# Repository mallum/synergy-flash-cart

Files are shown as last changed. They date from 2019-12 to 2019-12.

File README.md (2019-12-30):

# Synergy Flash Cart

A 'Flash Cart' for your DK Synergy synth... select & load ROM cartridge .crt files from the root of an SD card.

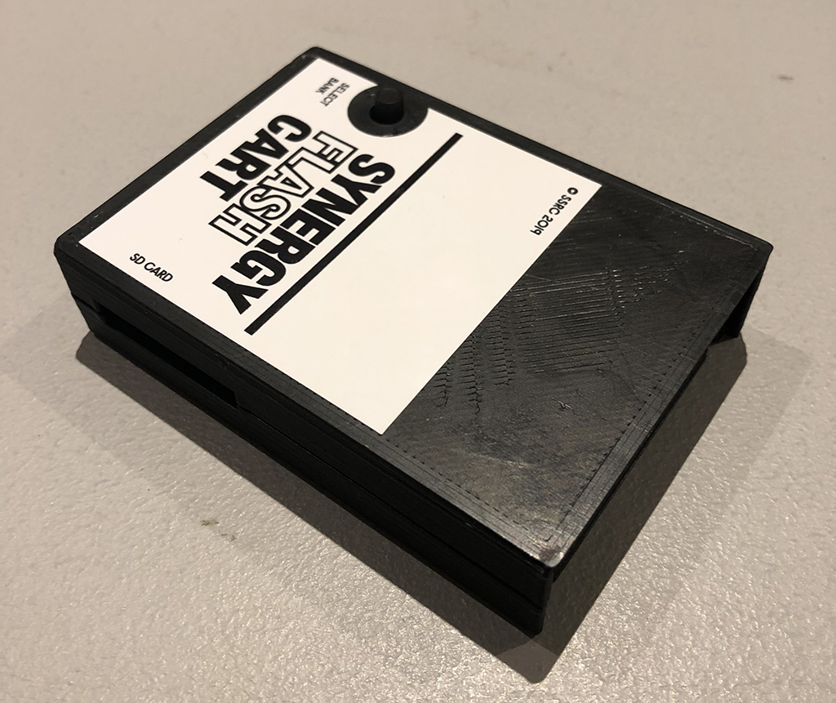
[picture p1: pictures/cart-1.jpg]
Image of Flash Cart


A single button cycles between .crt files placed on root of a fat formatted sd card. Top backlit character display shows currently active crt file. 

This repository contains the schematics, BOM, source code and 3D print files for a cartridge.

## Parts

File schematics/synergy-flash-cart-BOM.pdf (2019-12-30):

### synergy-cart rev005

Qty | Parts | Value | Package | Part num / Description
1 | R6 | 0R | R0603
1 | R19 | 1k | R0603
10 | R1, R2, R3, R4, R5, R7, R8, R45, R47, R48 | 10K | R0603
1 | R10 | 100k | R0603
1 | R9 | 5k | RTRIM4G/J | TS53YJ502MR10 (or similar)
2 | C26, C29 | 18pF | C0603
1 | C20 | 10n | C0603
9 | C2, C5, C7, C18, C30, C32, C33, C35, C58 | 100n | C0603
1 | C8 | 1uf | C0603
2 | C22, C24 | 2.2uf | C0805
2 | C1, C6 | 10uf | CT3216 | CA45-106K016AT (16V) Tantalum
1 | IC7 | REG1117 | SOT223 | AMS1117-3.3 (or similar)
1 | UC1 | STM32F405RGT6 | TQFP-10X10-64 | STM32F405RGT6
1 | CN1 | | SDCARD_SMT_AMPH_160611 | Amphenol 1010031336802 (or similar - check footprint)
1 | X1 | 52746-16 | 52746-16 | FPC Connector ZIF for SMT 0.5mm contacts bottom / AFC07-S16FCC-00 (or similar))
1 | Y1 | 8Mhz | CRYSTAL-SMD-5.0MM-3.2MM-2 | 7A-8.00MAAJ-T (or similar)
1 | BANK_SEL | SWITCH-MOMENTARY-2PTH | TACTILE-PTH | NOT NEEDED (TL1105SPF250Q)
1 | LED | | CHIPLED_1206 | NOT NEEDED (debug)
1 | J3 | M05_NOSILK_1SQ | M05_NOSILK_1SQ | NOT NEEDED (programming header)
1 | RST | T1107A-6_3.8_2.5 | SW-TAKT_6X3.5_SMD | NOT NEEDED (reset switch)
1 | PWR | | 1X02 | NOT NEEDED (alt power source for programming)
1 | G-T-R | | 1X03 | NOT NEEDED (Debug serial port)
1 | SYNERGYCART | SYNERGY_CARTSYNER | SYNERGY_CART | NOT NEEDED (PCB layout)

Also needs display - buydisplay.com ERM801FS-1 , button cap Sifam PB04/51/000, printed case, m3 threaded insert, screw, sticker (ALL NOT NEEDED for pcb cart)

All caps at least 10v Ceramic unless specced. All resistors 1% at least 0.1 watt

1

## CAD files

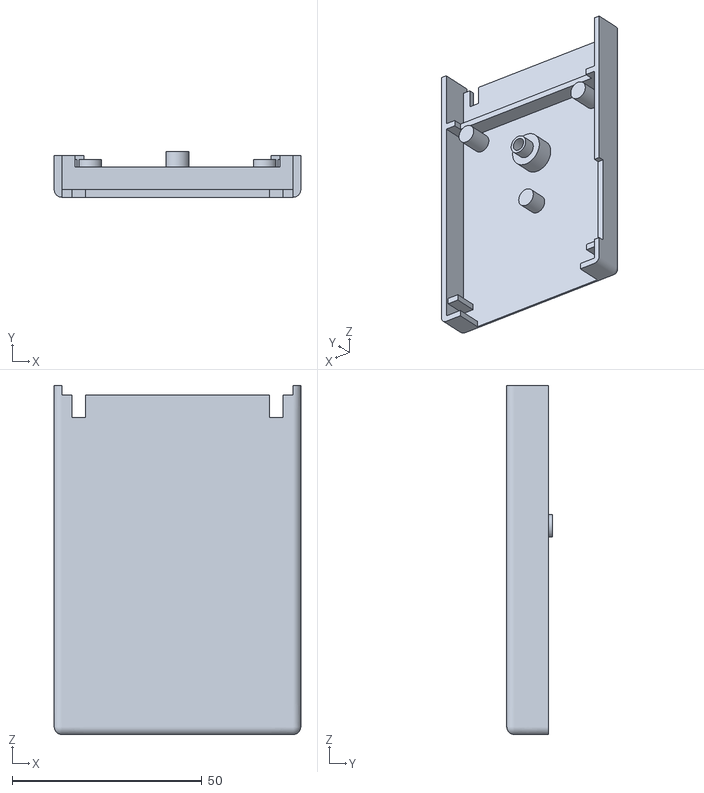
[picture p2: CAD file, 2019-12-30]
form/cart-bottom-v15.stl
65.0 x 12.0 x 92.0

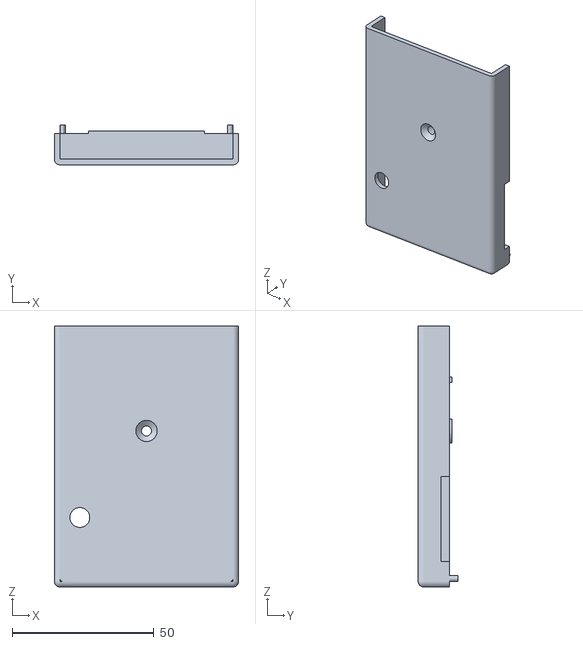
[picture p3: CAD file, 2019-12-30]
form/cart-top-v10.stl
65.0 x 14.0 x 92.0

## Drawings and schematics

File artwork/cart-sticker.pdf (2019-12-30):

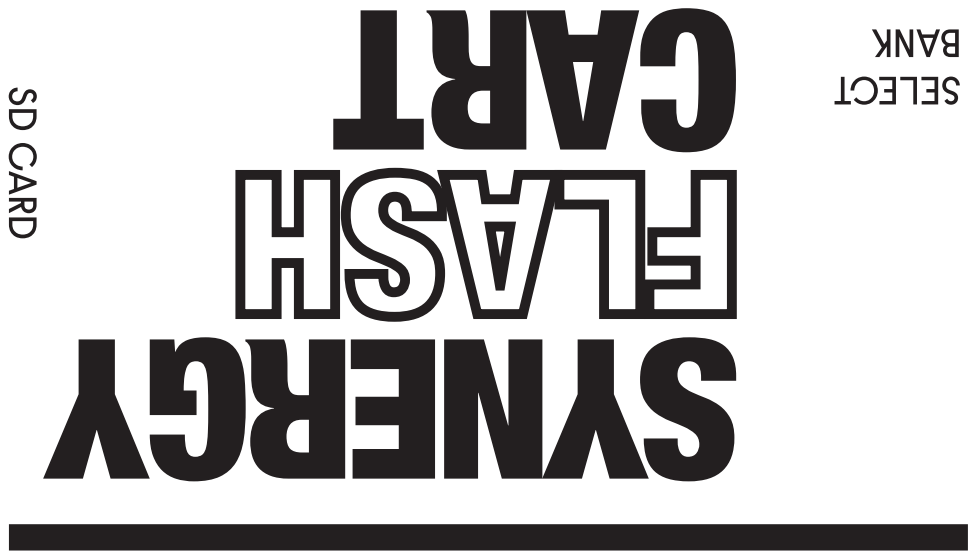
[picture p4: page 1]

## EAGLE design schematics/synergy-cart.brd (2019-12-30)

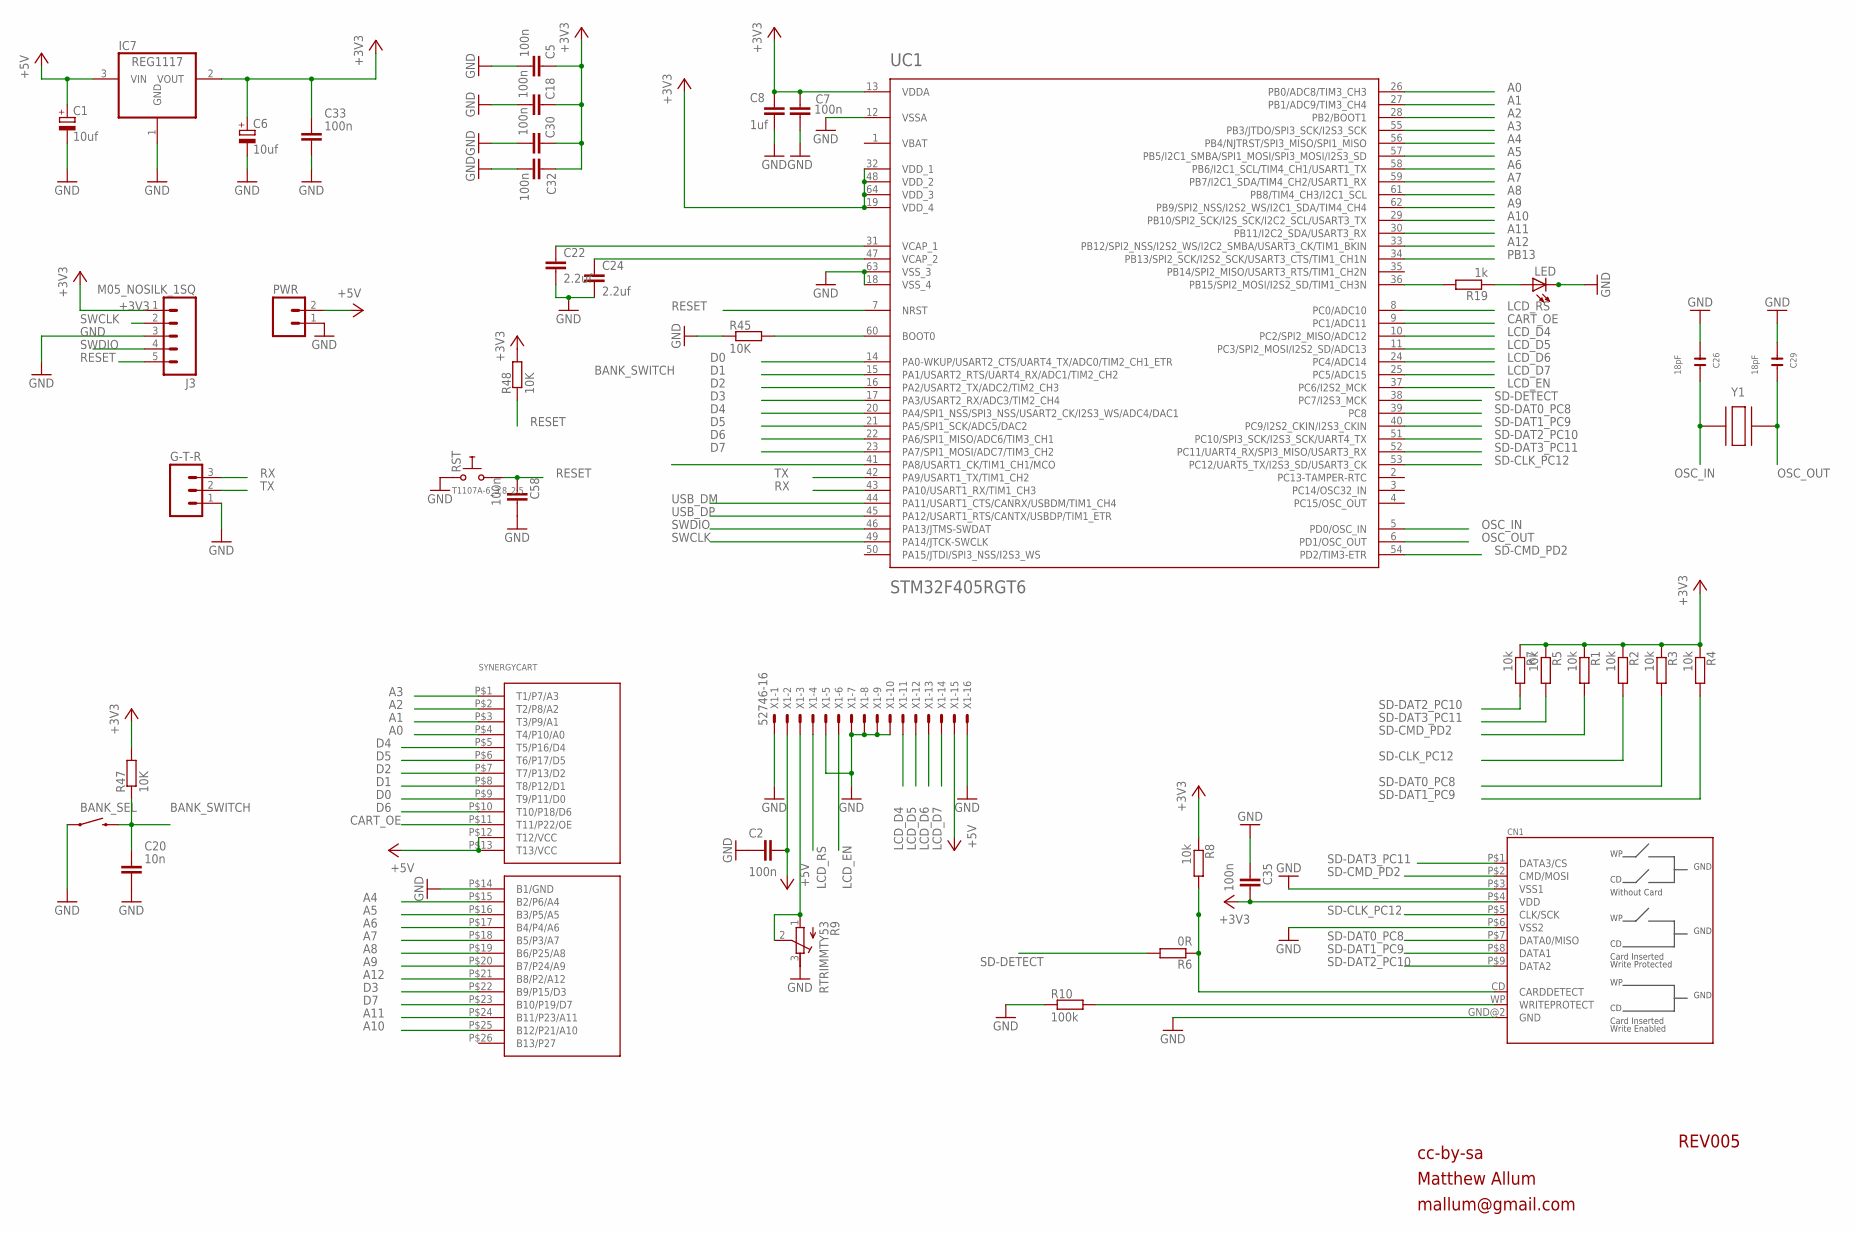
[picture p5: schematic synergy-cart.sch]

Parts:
BANK_SEL: SWITCH-MOMENTARY-2PTH; TACTILE-PTH
C1, C6: 10uf; CT3216
C2, C5, C7, C18, C30, C32, C33, C35, C58: 100n; C0603
C8: 1uf; C0603
C20: 10n; C0603
C22, C24: 2.2uf; C0805
C26, C29: 18pF; C0603
CN1: SDCARD160611; SDCARD_SMT_AMPH_160611
G-T-R: M03PTH; 1X03
IC7: REG1117; SOT223
J3: M05_NOSILK_1SQ
LED: LEDCHIPLED_1206; CHIPLED_1206
PWR: M02PTH; 1X02
R1, R2, R3, R4, R5, R7, R8: 10k; R0603
R6: 0R; R0603
R9: RTRIMMTY53; RTRIMTY53
R10: 100k; R0603
R19: 1k; R0603
R45, R47, R48: 10K; R0603
RST: T1107A-6_3.8_2.5; SW-TAKT_6X3.5_SMD
SYNERGYCART: SYNERGY_CARTSYNER; SYNERGY_CART
UC1: STM32F405RGT6; TQFP-10X10-64
X1: 52746-16
Y1: CRYSTAL-2; CRYSTAL-SMD-5.0MM-3.2MM-2

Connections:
+3V3: C5.1, C6.- (+), C7.1, C8.1, C18.1, C30.1, C32.1, C33.1, C35.1, CN1.P$4 (VDD), IC7.2 (VOUT), J3.1, R1.1, R2.1, R3.1, R4.1, R5.1, R7.1, R8.1, R47.2, R48.2, UC1.13 (VDDA), UC1.19 (VDD_4), UC1.32 (VDD_1), UC1.48 (VDD_2), UC1.64 (VDD_3)
+5V: C1.- (+), C2.1, IC7.3 (VIN), PWR.2, SYNERGYCART.P$12 (T12/VCC), SYNERGYCART.P$13 (T13/VCC), X1.2, X1.15
A0: SYNERGYCART.P$4 (T4/P10/A0), UC1.26 (PB0/ADC8/TIM3_CH3)
A1: SYNERGYCART.P$3 (T3/P9/A1), UC1.27 (PB1/ADC9/TIM3_CH4)
A2: SYNERGYCART.P$2 (T2/P8/A2), UC1.28 (PB2/BOOT1)
A3: SYNERGYCART.P$1 (T1/P7/A3), UC1.55 (PB3/JTDO/SPI3_SCK/I2S3_SCK)
A4: SYNERGYCART.P$15 (B2/P6/A4), UC1.56 (PB4/NJTRST/SPI3_MISO/SPI1_MISO)
A5: SYNERGYCART.P$16 (B3/P5/A5), UC1.57 (PB5/I2C1_SMBA/SPI1_MOSI/SPI3_MOSI/I2S3_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)
A6: SYNERGYCART.P$17 (B4/P4/A6), UC1.58 (PB6/I2C1_SCL/TIM4_CH1/USART1_TX)
A7: SYNERGYCART.P$18 (B5/P3/A7), UC1.59 (PB7/I2C1_SDA/TIM4_CH2/USART1_RX)
A8: SYNERGYCART.P$19 (B6/P25/A8), UC1.61 (PB8/TIM4_CH3/I2C1_SCL)
A9: SYNERGYCART.P$20 (B7/P24/A9), UC1.62 (PB9/SPI2_NSS/I2S2_WS/I2C1_SDA/TIM4_CH4)
A10: SYNERGYCART.P$25 (B12/P21/A10), UC1.29 (PB10/SPI2_SCK/I2S_SCK/I2C2_SCL/USART3_TX)
A11: SYNERGYCART.P$24 (B11/P23/A11), UC1.30 (PB11/I2C2_SDA/USART3_RX)
A12: SYNERGYCART.P$21 (B8/P2/A12), UC1.33 (PB12/SPI2_NSS/I2S2_WS/I2C2_SMBA/USART3_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)
BANK_SWITCH: BANK_SEL.3 (2), C20.1, R47.1, UC1.41 (PA8/USART1_CK/TIM1_CH1/MCO)
CART_OE: SYNERGYCART.P$11 (T11/P22/OE), UC1.9 (PC1/ADC11)
D0: SYNERGYCART.P$9 (T9/P11/D0), UC1.14 (PA0-WKUP/USART2_CTS/UART4_TX/ADC0/TIM2_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)
D1: SYNERGYCART.P$8 (T8/P12/D1), UC1.15 (PA1/USART2_RTS/UART4_RX/ADC1/TIM2_CH2)
D2: SYNERGYCART.P$7 (T7/P13/D2), UC1.16 (PA2/USART2_TX/ADC2/TIM2_CH3)
D3: SYNERGYCART.P$22 (B9/P15/D3), UC1.17 (PA3/USART2_RX/ADC3/TIM2_CH4)
D4: SYNERGYCART.P$5 (T5/P16/D4), UC1.20 (PA4/SPI1_NSS/SPI3_NSS/USART2_CK/I2S3_WS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)
D5: SYNERGYCART.P$6 (T6/P17/D5), UC1.21 (PA5/SPI1_SCK/ADC5/DAC2)
D6: SYNERGYCART.P$10 (T10/P18/D6), UC1.22 (PA6/SPI1_MISO/ADC6/TIM3_CH1)
D7: SYNERGYCART.P$23 (B10/P19/D7), UC1.23 (PA7/SPI1_MOSI/ADC7/TIM3_CH2)
GND: BANK_SEL.1, C1.+ (-), C2.2, C5.2, C6.+ (-), C7.2, C8.2, C18.2, C20.2, C22.2, C24.2, C26.2, C29.2, C30.2, C32.2, C33.2, C35.2, C58.1, CN1.GND@2 (GND), CN1.P$3 (VSS1), CN1.P$6 (VSS2), G-T-R.1, IC7.1 (GND), J3.3, LED.C, PWR.1, R9.3 (E), R10.1, R45.1, RST.P$1 (0), SYNERGYCART.P$14 (B1/GND), UC1.12 (VSSA), UC1.18 (VSS_4), UC1.63 (VSS_3), X1.1, X1.5, X1.7, X1.8, X1.9, X1.10, X1.16
LCD_D4: UC1.10 (PC2/SPI2_MISO/ADC12), X1.11
LCD_D5: UC1.11 (PC3/SPI2_MOSI/I2S2_SD/ADC13), X1.12
LCD_D6: UC1.24 (PC4/ADC14), X1.13
LCD_D7: UC1.25 (PC5/ADC15), X1.14
LCD_EN: UC1.37 (PC6/I2S2_MCK), X1.6
LCD_RS: UC1.8 (PC0/ADC10), X1.4
unnamed: R19.2, UC1.36 (PB15/SPI2_MOSI/I2S2_SD/TIM1_CH3N)
unnamed: R45.2, UC1.60 (BOOT0)
unnamed: CN1.CD (CARDDETECT), R6.1, R8.2
unnamed: CN1.WP (WRITEPROTECT), R10.2
unnamed: R9.1 (A), R9.2 (S), X1.3
unnamed: LED.A, R19.1
unnamed: C22.1, UC1.31 (VCAP_1)
unnamed: C24.1, UC1.47 (VCAP_2)
OSC_IN: C26.1, UC1.5 (PD0/OSC_IN), Y1.2
OSC_OUT: C29.1, UC1.6 (PD1/OSC_OUT), Y1.1
PB13: UC1.34 (PB13/SPI2_SCK/I2S2_SCK/USART3_CTS/TIM1_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)
RESET: C58.2, J3.5, R48.1, RST.P$2 (1), UC1.7 (NRST)
RX: G-T-R.3, UC1.43 (PA10/USART1_RX/TIM1_CH3)
SD-CLK_PC12: CN1.P$5 (CLK/SCK), R2.2, UC1.53 (PC12/UART5_TX/I2S3_SD/USART3_CK)
SD-CMD_PD2: CN1.P$2 (CMD/MOSI), R1.2, UC1.54 (PD2/TIM3-ETR)
SD-DAT0_PC8: CN1.P$7 (DATA0/MISO), R3.2, UC1.39 (PC8)
SD-DAT1_PC9: CN1.P$8 (DATA1), R4.2, UC1.40 (PC9/I2S2_CKIN/I2S3_CKIN)
SD-DAT2_PC10: CN1.P$9 (DATA2), R7.2, UC1.51 (PC10/SPI3_SCK/I2S3_SCK/UART4_TX)
SD-DAT3_PC11: CN1.P$1 (DATA3/CS), R5.2, UC1.52 (PC11/UART4_RX/SPI3_MISO/USART3_RX)
SD-DETECT: R6.2, UC1.38 (PC7/I2S3_MCK)
SWCLK: J3.2, UC1.49 (PA14/JTCK-SWCLK)
SWDIO: J3.4, UC1.46 (PA13/JTMS-SWDAT)
TX: G-T-R.2, UC1.42 (PA9/USART1_TX/TIM1_CH2)
USB_DM: UC1.44 (PA11/USART1_CTS/CANRX/USBDM/TIM1_CH4)
USB_DP: UC1.45 (PA12/USART1_RTS/CANTX/USBDP/TIM1_ETR)
VBAT: UC1.1 (VBAT)

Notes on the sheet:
REV005
cc-by-sa
Matthew Allum
mallum@gmail.com

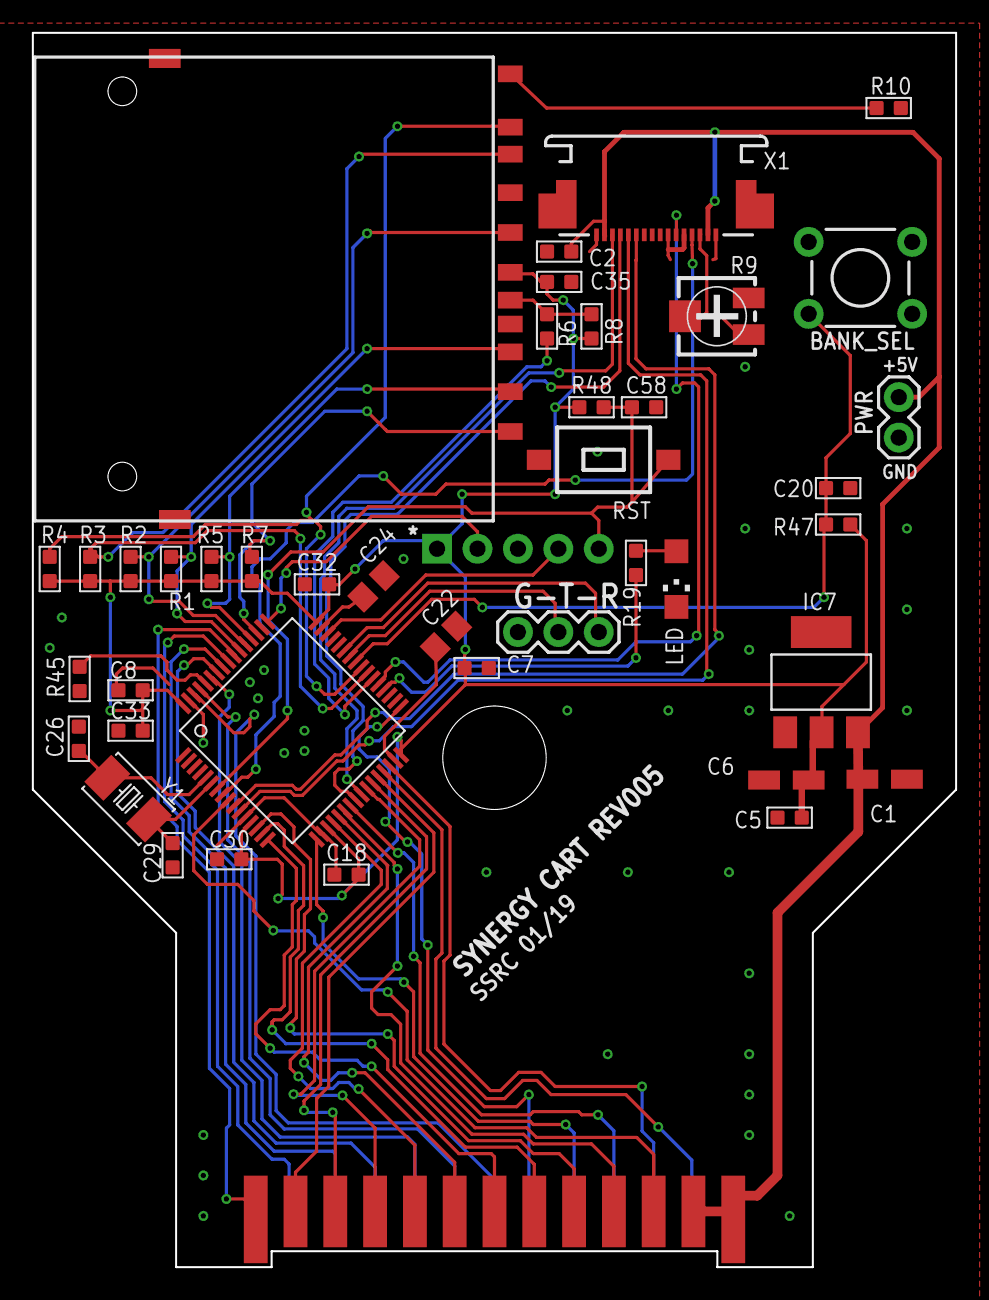
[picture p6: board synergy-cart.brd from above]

Board: 2 copper layers, 58.0 x 77.5 mm, 43 parts (0 on the bottom side), 54 nets.

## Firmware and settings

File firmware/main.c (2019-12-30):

/* 

Copyright (c) 2019 Matthew Allum / Allum & Co ltd. 

All rights reserved.

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
*/

#include <stdbool.h>
#include <math.h>
#include <limits.h>
#include <string.h>

#include "hw.h"

#include "sdcard.h"
#include "ff.h"
#include "diskio.h"

#define MAX_FILENAME_LEN 128
#define MAX_CART_FILENAMES 128

typedef struct _SynergyCartFile
{
  char      filename[MAX_FILENAME_LEN];
  uint16_t  size;
} SynergyCartFile;

SynergyCartFile _cart_files[MAX_CART_FILENAMES];
uint16_t _n_cart_files = 0;

#define CCRAM_SIZE (64 * 1024)
uint8_t _ccram[CCRAM_SIZE] __attribute__((section(".ccmram")));

#define ADDR_IN GPIOB->IDR
#define DATA_OUT GPIOA->ODR

void sort_carts()
{
  int i,j;

  for (i=0;i<_n_cart_files;i++)
    for (j=i+1;j<_n_cart_files; j++)
      if (strcmp(_cart_files[i].filename, _cart_files[j].filename) > 0)
	{
	  SynergyCartFile tmp;
	  /* meh.. */
	  memcpy((void*)tmp.filename, (void*)_cart_files[i].filename, MAX_FILENAME_LEN);
	  tmp.size = _cart_files[i].size;
	  memcpy((void*)_cart_files[i].filename, (void*)_cart_files[j].filename, MAX_FILENAME_LEN);
	  _cart_files[i].size = _cart_files[j].size;
	  memcpy((void*)_cart_files[j].filename, (void*)tmp.filename , MAX_FILENAME_LEN);
	  _cart_files[i].size = tmp.size;
	}
}

bool sd_load_cart(int index)
{
  volatile FATFS fs;   

  FIL fsrc;      
  uint32_t br, i = 0;
  FRESULT res;
  FILINFO finfo;
  uint8_t buf[256];
  char txt[9];
  
  res = f_open(&fsrc, _cart_files[index].filename, FA_OPEN_EXISTING | FA_READ);

  if (res != FR_OK)
    {
      tfp_printf("f_open failed\n");
      hw_lcd_clear();
      hw_lcd_put_str("SD Fail");
      return false;
    }

  do
    {
      res = f_read(&fsrc, (uint8_t *)buf, 256, (unsigned int*)&br);
      memcpy(&_ccram[i], buf, br);
      i += br;
    }
  while (res == FR_OK && br == 256 && i < CCRAM_SIZE);

  tfp_printf("read %i\n", i);

  /* fixme pull the name from the actual cart file itself */
  i = strlen(_cart_files[index].filename)-4;
  if (i>9) i=9;
  tfp_snprintf(txt, 9, "%s", _cart_files[index].filename+1);
  txt[i-1] = '\0';

  hw_lcd_clear();
  hw_lcd_put_str(txt);

  _cart_files[index].size = br;
  
  f_close(&fsrc);

  return true;
}

bool sd_get_carts(void)
{
  FATFS fs;  
  FIL fsrc;  
  uint32_t br, i; 
  FRESULT res;
  DIR dir;
  FILINFO fno;

  _n_cart_files = 0;
  
  disk_initialize(0);
  
  res = f_mount(0, &fs);

  if (res != FR_OK)
    {
      hw_lcd_clear();
      hw_lcd_put_str("SD Err!");
      return false;
    }
  
  res = f_opendir(&dir, "/");  /* Open the root */

  if (res == FR_OK)
    {
      while (true)
	{
	  res = f_readdir(&dir, &fno); /* Read a directory item */
	  if (res != FR_OK || fno.fname[0] == 0)
	    break;  /* Break on error or end of dir */
	  if (!(fno.fattrib & AM_DIR)) 
	    {
	      /* It is a file. */
	      i = strlen(fno.fname);
	      if (_n_cart_files < MAX_CART_FILENAMES && i > 4 && strncasecmp(".crt", (const char *)&fno.fname[i-4], 4) == 0)
		{
		  hw_lcd_clear();
		  hw_lcd_put_str(fno.fname);
		  tfp_snprintf(_cart_files[_n_cart_files++].filename, MAX_FILENAME_LEN, "/%s", fno.fname);
		}
            }
        }

      //f_closedir(&dir); no closedir in fatfs version used.. FIXME: need to update

      hw_lcd_clear();
      hw_lcd_put_str("Ready.");
    }

  if (_n_cart_files == 0)
    {
      hw_lcd_clear();
      hw_lcd_put_str("No CRTs!");
      return false;
    }

  sort_carts();
  
  return true;
}

void abort()		/* lazy disk problem stratergy.. reboot and rescan for card */
{
  while (GPIOA->IDR & GPIO_Pin_8)
    ;			/* loop unit button pressed */
  NVIC_SystemReset();	/* reboot */
}

int main(void)
{
  int     i = 0;
  bool    switch_was_low = true;
  uint8_t cart_index = 0;

  SysTick_Config(SystemCoreClock / 1000); /* Note interupts get turns off in main loop, this just for init */
  NVIC_SetPriority(SysTick_IRQn, 0x0);

  hw_rcc_set_frequency(SYSCLK_200_MHZ); /* turbo */

  /* CCM etc */
  RCC->APB2ENR |= 0 |  RCC_APB2ENR_SYSCFGEN ;
  SYSCFG->CMPCR |= SYSCFG_CMPCR_CMP_PD; 
  while ((SYSCFG->CMPCR & SYSCFG_CMPCR_READY) == 0);

  RCC_AHB1PeriphClockCmd(RCC_AHB1Periph_CCMDATARAMEN, ENABLE); 

  /* debug */
  hw_usart_dbg_init();
  tfp_printf("App up...\n");	/* debug, to serial */

  /* lcd */
  hw_lcd_init();
  tfp_printf("lcd inited...\n");
  
  hw_lcd_put_str("S");	/* Anim here...? */
  hw_delay_ms(100);
  hw_lcd_put_str("S");
  hw_delay_ms(100);
  hw_lcd_put_str("R");
  hw_delay_ms(100);
  hw_lcd_put_str("C");
  hw_delay_ms(500);

  /* Synergy interface pins up */  
  hw_init_gpio_data();
  hw_init_gpio_addr();
  hw_init_gpio_output_enable();

  /* SD card */
  if (!sd_get_carts())
    abort();

  if (!sd_load_cart(0))		
    abort();
    
  DATA_OUT = 0;

  __disable_irq();
  
  while (1)
    {
      if (!(GPIOC->IDR & GPIO_Pin_1))
	{
	  //GPIOA->BSRRL = GPIO_Pin_10; /* instrument - approx 120ns for a read.. OE cycle is approx 750ns  */
	  DATA_OUT = ((uint16_t)_ccram[ADDR_IN]) /* should really be DATA_OUT = DATA_OUT | _ccram[addr] .. but slower */;
	  //GPIOA->BSRRH = GPIO_Pin_10;
	}

      if (!(GPIOA->IDR & GPIO_Pin_8))
	{
	  if (switch_was_low)
	    {
	      if (++cart_index >= _n_cart_files)
		cart_index = 0;

	      if (!sd_load_cart(cart_index))
		abort();

	      switch_was_low = false;
	    }
	}
      else
	switch_was_low = true;
    }
  
}

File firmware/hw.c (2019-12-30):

/* 

Copyright (c) 2019 Matthew Allum / Allum & Co ltd. 

All rights reserved.

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
*/
  
#include "hw.h"

void NMI_Handler(void)
{
  while (1)
  {
  };
}

void HardFault_Handler(void)
{
  while (1)
  {
  };
}

void MemManage_Handler(void)
{
  while (1)
  {
  };
}

void BusFault_Handler(void)
{
  while (1)
  {
  };
}

void UsageFault_Handler(void)
{
  while (1)
  {
  };
}

void SVC_Handler(void)
{
  while (1)
  {
  };
}

void DebugMon_Handler(void)
{
  while (1)
  {
  };
}

void PendSV_Handler(void)
{
  while (1)
  {
  };
}


/* systick timing */

volatile uint32_t __msec;

uint32_t hw_get_ms()
{
  return __msec;
}

void hw_delay_ms(uint32_t ms)
{
  uint32_t MSS = __msec;
  while((__msec-MSS)<ms) asm volatile ("nop");
}

void hw_delay_no_systick(uint32_t usec) /* FIXME: very approx! */
{
  __IO uint32_t count = 0;
  const uint32_t utime = (120 * usec / 7);
  do
    {
      if ( ++count > utime )
	{
	  return ;
	}
    }
  while (1);
}

void SysTick_Handler(void)
{
  __msec++;
}

/* display */

#define LCD_PORT GPIOC

#define LCD_RS_PIN GPIO_Pin_0

#define LCD_DB4_PIN GPIO_Pin_2
#define LCD_DB5_PIN GPIO_Pin_3
#define LCD_DB6_PIN GPIO_Pin_4
#define LCD_DB7_PIN GPIO_Pin_5

#define LCD_ENABLE_PIN GPIO_Pin_6

enum LCD_FLAGS {
  LCD_COMMAND = 0x00,
  LCD_DATA = 0x10,
  LCD_CLEAR = 0x01,
  LCD_HOME = 0x02,
  LCD_ENTRY_MODE = 0x04,
  LCD_DISPLAY_STATUS = 0x08,
  LCD_CURSOR = 0x10,
  LCD_FUNCTION_SET = 0x20,
  LCD_SET_CGRAM_ADDRESS = 0x40,
  LCD_SET_DDRAM_ADDRESS = 0x80,

  LCD_SHIFT = 0x01,
  LCD_NO_SHIFT = 0x00,
  LCD_CURSOR_INCREMENT = 0x02,
  LCD_CURSOR_NO_INCREMENT = 0x00,
  LCD_DISPLAY_ON = 0x04,
  LCD_DISPLAY_OFF = 0x00,
  LCD_CURSOR_ON = 0x02,
  LCD_CURSOR_OFF = 0x00,
  LCD_BLINKING_ON = 0x01,
  LCD_BLINKING_OFF = 0x00,

  LCD_8_BITS = 0x10,
  LCD_4_BITS = 0x00,

  LCD_2_LINE = 0x08,
  LCD_1_LINE = 0x00,

  LCD_LARGE_FONT = 0x04,
  LCD_SMALL_FONT = 0x00,
};

void hw_lcd_strobe(void)
{
  hw_delay_no_systick(1000);
  GPIO_SetBits(LCD_PORT, LCD_ENABLE_PIN);
  hw_delay_no_systick(1000);
  GPIO_ResetBits(LCD_PORT, LCD_ENABLE_PIN);
}

void hw_lcd_send_nibble(uint8_t c)
{
  if(c & 0x8)
    GPIO_SetBits(LCD_PORT, LCD_DB7_PIN);
  else
    GPIO_ResetBits(LCD_PORT, LCD_DB7_PIN);

  if(c & 0x4)
    GPIO_SetBits(LCD_PORT, LCD_DB6_PIN);
  else
    GPIO_ResetBits(LCD_PORT, LCD_DB6_PIN);

  if(c & 0x2)
    GPIO_SetBits(LCD_PORT, LCD_DB5_PIN);
  else
    GPIO_ResetBits(LCD_PORT, LCD_DB5_PIN);

  if(c & 0x1)
    GPIO_SetBits(LCD_PORT, LCD_DB4_PIN);
  else
    GPIO_ResetBits(LCD_PORT, LCD_DB4_PIN);
}

void hw_lcd_data(uint8_t c)
{
  GPIO_SetBits(LCD_PORT, LCD_RS_PIN);
  hw_lcd_send_nibble(c>>4);
  hw_lcd_strobe();
  hw_lcd_send_nibble(c);
  hw_lcd_strobe();
  GPIO_ResetBits(LCD_PORT, LCD_RS_PIN);
}

void hw_lcd_cmd(uint8_t c)
{
  GPIO_ResetBits(LCD_PORT, LCD_RS_PIN);
  hw_lcd_send_nibble(c>>4);
  hw_lcd_strobe();
  hw_lcd_send_nibble(c);
  hw_lcd_strobe();
}

void
hw_lcd_init()
{
  GPIO_InitTypeDef g;
  uint8_t i;
  
  RCC_AHB1PeriphClockCmd(RCC_AHB1Periph_GPIOC, ENABLE);

  g.GPIO_Pin = LCD_DB4_PIN|LCD_RS_PIN|LCD_DB5_PIN|LCD_DB6_PIN|LCD_DB7_PIN|LCD_ENABLE_PIN;
  g.GPIO_Mode = GPIO_Mode_OUT;
  g.GPIO_OType = GPIO_OType_PP;
  g.GPIO_Speed = GPIO_Speed_50MHz;
  g.GPIO_PuPd = GPIO_PuPd_NOPULL;
  GPIO_Init(LCD_PORT, &g);

  GPIO_ResetBits(LCD_PORT, LCD_DB4_PIN|LCD_RS_PIN|LCD_DB5_PIN|LCD_DB6_PIN|LCD_DB7_PIN|LCD_ENABLE_PIN);

  hw_delay_ms(50); // wait for warm up

  // Set to 4 bit operation.
  for (i = 0; i < 3; ++i)
    {
      hw_lcd_cmd ((LCD_FUNCTION_SET | LCD_8_BITS) >> 4);
      hw_delay_ms(5);
    }
  hw_lcd_cmd ((LCD_FUNCTION_SET | LCD_4_BITS) >> 4);
  
  hw_delay_ms(20);
  
  /* 1 line */
  hw_lcd_cmd (LCD_FUNCTION_SET | LCD_4_BITS | LCD_1_LINE | LCD_SMALL_FONT);

  hw_lcd_cmd (LCD_DISPLAY_STATUS | LCD_DISPLAY_ON | LCD_CURSOR_OFF | LCD_BLINKING_OFF);
  hw_lcd_cmd (LCD_ENTRY_MODE | LCD_CURSOR_INCREMENT | LCD_NO_SHIFT);
  hw_lcd_cmd (LCD_CLEAR);
  hw_lcd_cmd (LCD_HOME);
}

void hw_lcd_put_char(uint8_t c)
{
  if  ( (c < 8)
	|| ((c >= 0x20) && (c <= 0x7f))
	|| ((c >= 0xa0) && (c <= 0xff))) // check if 'c' is within display boundry
    {
      hw_lcd_data(c);
    }
}

void hw_lcd_put_str(char *s)
{
  uint8_t i=0;
  
  while(s[i] != '\0' && i < 8)
    hw_lcd_put_char(s[i++]);
}

void hw_lcd_clear()
{
  hw_lcd_cmd(0x01);
}

void hw_lcd_make_char(uint8_t index, uint8_t charmap[])
{
  index &= 0x7; // we only have 8 locations 0-7
  hw_lcd_cmd(LCD_SET_CGRAM_ADDRESS | (index << 3));

  for (int i=0; i<8; i++)
    hw_lcd_data(charmap[i]);
}

void _hw_usart_init(int baudrate)
{
  GPIO_InitTypeDef g;
  USART_InitTypeDef usart_init;

  RCC_AHB1PeriphClockCmd(RCC_AHB1Periph_GPIOA, ENABLE);
  
  // sort out clocks
  RCC_APB2PeriphClockCmd(RCC_APB2Periph_USART1, ENABLE);

  /* Configure USART2 Tx (PA.02) as alternate function push-pull */
  g.GPIO_Pin = GPIO_Pin_9;
  g.GPIO_Speed = GPIO_Speed_50MHz;
  g.GPIO_Mode = GPIO_Mode_AF;
  g.GPIO_OType = GPIO_OType_PP;
  g.GPIO_PuPd = GPIO_PuPd_UP;
  GPIO_Init(GPIOA, &g);

  // Map USART2 to A.02
  GPIO_PinAFConfig(GPIOA, GPIO_PinSource9, GPIO_AF_USART1);
  // Initialize USART

  usart_init.USART_BaudRate = baudrate;
  usart_init.USART_WordLength = USART_WordLength_8b;
  usart_init.USART_StopBits = USART_StopBits_1;
  usart_init.USART_Parity = USART_Parity_No;
  usart_init.USART_HardwareFlowControl = USART_HardwareFlowControl_None;
  usart_init.USART_Mode = USART_Mode_Tx;

  /* Configure USART */
  USART_Init(USART1, &usart_init);
  /* Enable the USART */
  USART_Cmd(USART1, ENABLE);
}


static void USART_putc(USART_TypeDef* USARTx, unsigned char c)
{
  while (USART_GetFlagStatus(USARTx, USART_FLAG_TXE) == RESET);

  USART_SendData(USARTx, c);
}

void hw_usart_dbg_init()
{
  _hw_usart_init(115200);
  init_printf((void*)USART1,(putcf)USART_putc);
}

/* usart end */


void hw_init_gpio_output_enable(void)
{
  GPIO_InitTypeDef  g;

  RCC_AHB1PeriphClockCmd(RCC_AHB1Periph_GPIOC, ENABLE);

  g.GPIO_Pin = GPIO_Pin_1;
  g.GPIO_Mode = GPIO_Mode_IN;
  g.GPIO_OType = GPIO_OType_PP;
  g.GPIO_Speed = GPIO_Speed_100MHz;
  g.GPIO_PuPd = GPIO_PuPd_UP;
  GPIO_Init(GPIOC, &g);
}

void hw_init_gpio_addr(void)
{
  GPIO_InitTypeDef  g;

  RCC_AHB1PeriphClockCmd(RCC_AHB1Periph_GPIOB, ENABLE);
  
  g.GPIO_Pin = 
    GPIO_Pin_0 | GPIO_Pin_1 | GPIO_Pin_2 | GPIO_Pin_3 | 
    GPIO_Pin_4 | GPIO_Pin_5 | GPIO_Pin_6 | GPIO_Pin_7 | 
    GPIO_Pin_8 | GPIO_Pin_9 | GPIO_Pin_10 | GPIO_Pin_11 | 
    GPIO_Pin_12;
  g.GPIO_Mode = GPIO_Mode_IN;
  g.GPIO_OType = GPIO_OType_PP;
  g.GPIO_Speed = GPIO_Speed_100MHz;
  g.GPIO_PuPd = GPIO_PuPd_DOWN;
  GPIO_Init(GPIOB, &g);
}

void hw_init_gpio_data(void)
{
  GPIO_InitTypeDef  g;

  RCC_AHB1PeriphClockCmd(RCC_AHB1Periph_GPIOA, ENABLE);
  
  g.GPIO_Pin = GPIO_Pin_0 | GPIO_Pin_1 | GPIO_Pin_2 | GPIO_Pin_3 | 
    GPIO_Pin_4 | GPIO_Pin_5 | GPIO_Pin_6 | GPIO_Pin_7 | GPIO_Pin_10 ; /* 10 for debug */
  g.GPIO_Mode = GPIO_Mode_OUT;
  g.GPIO_OType = GPIO_OType_PP;
  g.GPIO_Speed = GPIO_Speed_100MHz;
  g.GPIO_PuPd = GPIO_PuPd_NOPULL;
  GPIO_Init(GPIOA, &g);
}
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

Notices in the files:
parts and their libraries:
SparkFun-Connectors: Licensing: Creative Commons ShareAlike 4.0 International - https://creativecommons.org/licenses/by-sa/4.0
